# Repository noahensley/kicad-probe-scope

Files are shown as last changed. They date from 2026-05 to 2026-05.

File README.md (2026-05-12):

# ESProbeScope3300

A KiCad PCB design created for ETEC 3300. The board is built around the **ESP32-S2FN4R2** and combines USB-C connectivity, 2.4 GHz Wi-Fi (via an on-board chip antenna), a battery charging circuit, an LDO power rail, an audio amplifier, an LCD interface, RGB status LEDs, and a multi-button probe input — all in a single compact design.

---

## Project structure

```
kicad-probe-scope/
├── ESProbeScope3300.kicad_pcb   # PCB layout
├── ESProbeScope3300.kicad_sch   # Schematic
├── ESProbeScope3300.kicad_pro   # Project file
├── sym-lib-table                # Project-scoped symbol library table
│
├── libs/
│   ├── PartsLibrary3300.kicad_sym       # Symbol library
│   └── PartsLibrary3300.pretty/         # Footprint library
│       └── *.kicad_mod
│
├── fab/
│   ├── gerbers/                 # Copper, mask, silkscreen, edge cuts
│   ├── ESProbeScope3300-PTH.drl
│   ├── ESProbeScope3300-NPTH.drl
│   └── ESProbeScope3300-job.gbrjob
│
└── doc/
    ├── schematic.pdf
    └── bom.xlsx
```

---

## Schematic

A PDF export of the schematic is available at [doc/schematic.pdf](doc/schematic.pdf) for viewing without KiCad.

---

## Key components

| Ref | Part | Function |
|-----|---|---|
| U1 | ESP32-S2FN4R2 | Main MCU with integrated 2.4 GHz Wi-Fi |
| ANT1 | Johanson 2450AT42B100E | 2.4 GHz chip antenna |
| J1 | GCT USB4110-GF-A | USB 2.0 Type-C connector |
| IC3 | MPS MP2664GG | Li-ion battery charger |
| IC1, IC2 | XC8110AA01MR-G | LDO voltage regulators |
| VR1 | ON Semi NCP114ASN330T1G | 3.3 V LDO |
| IC4 | PAM8301 | Class-D audio amplifier |
| LCD1 | Molex 527450897 | LCD flex connector |
| XTAL1 | EXS00A-CS14526 | Crystal oscillator |
| LED1, LED2 | B38G3RGB-10D0003H2U1930 | RGB status LEDs |
| S1–S8 | Alps SKRPABE010 | Tactile pushbuttons |
| SW1 | C&K JS102011SAQN | Slide power switch |
| X3 | — | Probe input header |

---

## Footprint and symbol libraries

All symbols and footprints are in `libs/PartsLibrary3300.kicad_sym` and `libs/PartsLibrary3300.pretty/`. Both are linked via `${KIPRJMOD}` in `sym-lib-table` and the project footprint library table, so they resolve automatically when the project is opened in KiCad regardless of where it is cloned.

Footprints originate from the KiCad standard library, SnapEDA, and manufacturer-published CAD data (Johanson Technology, Walsin, Molex, GCT). Attribution is noted in the footprint description fields within the library files themselves.

---

## License

MIT — see [LICENSE](LICENSE).

---

## Acknowledgements

- [KiCad EDA](https://www.kicad.org/) and the KiCad Libraries contributors
- [SnapEDA](https://www.snapeda.com) for component models
- Johanson Technology, Walsin Technology, Molex, GCT, and other component manufacturers for publishing CAD data

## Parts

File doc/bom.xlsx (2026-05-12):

ETEC3300 Project 2026 — Bill of Materials
Item # | *Ref Des | *Qty | Manufacturer | *Mfg Part # | Description / Value | *Package | Type
1 | ANT1 | 1 | Johanson Technology Inc. | 2450AT42B100 | RF ANTENNA Chip Solder Surface Mount | Custom SMT 2450AT42B100 | SMD
2 | C1, C2, C5, C13, C17 | 5 | Walsin Technology Corporation | 0603B105K250CT | 1 µF ±10% 25V Ceramic Capacitor X7R 0603 (1608 Metric) | C0603 | SMD
3 | C3 | 1 | Cal-Chip Electronics, Inc. | GMC02CG1R0C50NT | 1 pF ±0.25pF 50V Ceramic Capacitor C0G, NP0 0201 (0603 Metric) | C0603 | SMD
4 | C4 | 1 |  |  | DNP | C0603 | DNP
5 | C6 | 1 | Walsin Technology Corporation | 0603B101K500CT | 100 pF ±10% 50V Ceramic Capacitor X7R 0603 (1608 Metric) | C0603 | SMD
6 | C7, C12, C22, C25 | 4 | Cal-Chip Electronics, Inc. | GMC21X5R106M6R3NT | 10 µF ±20% 6.3V Ceramic Capacitor X5R 0805 (2012 Metric) | C0805 | SMD
7 | C8, C9, C11, C14, C15, C16, C19, C20, C23, C24, C26 | 11 | Walsin Technology Corporation | 0603B104M500CT | 0.1 µF ±20% 50V Ceramic Capacitor X7R 0603 (1608 Metric) | C0603 | SMD
8 | C10 | 1 | Taiyo Yuden | LMK107BJ475KA-T | 4.7 µF ±10% 10V Ceramic Capacitor X5R 0603 (1608 Metric) | C0603 | SMD
9 | C18, C21 | 2 | Walsin Technology Corporation | 0603N150J500CT | 15 pF ±5% 50V Ceramic Capacitor C0G, NP0 0603 (1608 Metric) | C0603 | SMD
10 | D1 | 1 | Diodes Incorporated | DDZ9684Q-7 | Zener Diode 3.3 V 500 mW ±5% Surface Mount SOD-123 | SOD123 | SMD
11 | IC1, IC5 | 2 | Torex Semiconductor Ltd | XC8110AA01MR-G | Power Switch/Driver 1:1 P-Channel 500mA SOT-25 | SOT25 | SMD
12 | IC2 | 1 | Monolithic Power Systems Inc. | MP2664GG-0000-Z | Charger IC Lithium Ion/Polymer 10-QFN (2x2) | QFN10 | SMD
13 | IC3 | 1 | Espressif Systems | ESP32-S2FH4 | WiFi 802.11b/g/n Transceiver Module 2.4GHz Antenna Not Included Surface Mount | 56-VFQFN Exposed Pad | SMD
14 | IC4 | 1 | Diodes Incorporated | PAM8301AAF | Amplifier IC 1-Channel (Mono) Class D SOT-23-6 | SOT23-6 | SMD
15 | L1 | 1 | Johanson Technology Inc. | LRC0402CS3N3GV001T | 3.3 nH Unshielded Multilayer Inductor 300 mA 190mOhm Max 0402 (1005 Metric) | L0402 | SMD
16 | L2 | 1 | Johanson Technology Inc. | LRC0603CS1N5GV001T | 1.5 nH Unshielded Multilayer Inductor 300 mA 100mOhm Max 0603 (1608 Metric) | L0603 | SMD
17 | LCD1 | 1 | Molex | 527450897 | 8 Position Connector Contacts, Top 0.020" (0.50mm) Surface Mount, Right Angle | MOLEX_FPC_527450897 | SMD
18 | LED1, LED2 | 2 | Harvatek Corporation | B38G3RGB-10D0003H2U1930 | Red, Green, Blue (RGB) LED Indication - Discrete 2V Red, 3V Green, 3V Blue 0606 (1616 Metric) | 0606_RGB_LED | SMD
19 | PROBE | 1 |  | DNP | - | MA03-2-05_3x2_1.27MM_PITCH_MALE_PIN_HEADER | DNP
20 | R1 | 1 | YAGEO | RC0603FR-070RL | 0 Ohms Jumper 0.1W, 1/10W Chip Resistor 0603 (1608 Metric) Moisture Resistant Thick Film | R0603 | 0603 (1608 Metric)
21 | R2, R3, R19, R20 | 4 | YAGEO | RC0603FR-07100KL | 100 kOhms ±1% 0.1W, 1/10W Chip Resistor 0603 (1608 Metric) Moisture Resistant Thick Film | R0603 | 0603 (1608 Metric)
22 | R4 | 1 | YAGEO | RC0603FR-07300KL | 300 kOhms ±1% 0.1W, 1/10W Chip Resistor 0603 (1608 Metric) Moisture Resistant Thick Film | R0603 | 0603 (1608 Metric)
23 | R5, R6 | 2 | YAGEO | RC0603FR-075K1L | 5.1 kOhms ±1% 0.1W, 1/10W Chip Resistor 0603 (1608 Metric) Moisture Resistant Thick Film | R0603 | 0603 (1608 Metric)
24 | R8, R7, R9, R10, R11, R12, R22 | 7 | YAGEO | RC0603FR-0710KL | 10 kOhms ±1% 0.1W, 1/10W Chip Resistor 0603 (1608 Metric) Moisture Resistant Thick Film | R0603 | 0603 (1608 Metric)
25 | R13, R14, R15, R16, R17, R18, R23 | 7 | YAGEO | RC0603FR-071KL | 1 kOhms ±1% 0.1W, 1/10W Chip Resistor 0603 (1608 Metric) Moisture Resistant Thick Film | R0603 | 0603 (1608 Metric)
26 | R21 | 1 | YAGEO | RC0603FR-0722RL | 22 Ohms ±1% 0.1W, 1/10W Chip Resistor 0603 (1608 Metric) Moisture Resistant Thick Film | R0603 | 0603 (1608 Metric)
27 | S0, S1, S2, S3, S4, SW_BOOT, SW_PWR, SW_RST | 8 | Alps Alpine | SKRPABE010 | Tactile Switch SPST-NO Top Actuated Surface Mount | ALPS_TACT_SKRPABE010 | SMD
28 | SPK | 1 | Molex | 53047-02 | Connector Header Through Hole 2 position 0.049" (1.25mm) | 53047-02 | TH
29 | SW1 | 1 | C&K | JS102011SAQN | Slide Switch SPDT Surface Mount, Right Angle | JS102011SAQN | SMD
30 | VR1 | 1 | onsemi | NCP114 | Linear Voltage Regulator IC Positive Fixed 1 Output 300mA 5-TSOP | TSOP-5 | SMD
31 | X1 | 1 |  | USBC_GCT_USB4110 |  | USBC_GCT_USB4110
32 | X2 | 1 | JST Sales America Inc. | B2B-PH-K-S | Connector Header Through Hole 2 position 0.079" (2.00mm) | B2B-PH-K-S_2MM_JST_CONNECTOR | TH
33 | X3 | 1 | Harwin Inc. | M20-9950245 | Connector Header Through Hole, Right Angle 4 position 0.100" (2.54mm) | MA02-2_2x2_RA_Male_Header | TH
34 | XTAL | 1 | NDK (NIHON DEMPA KOGYO CO., LTD) | NX3225SA | 32 MHz ±15ppm Crystal 8pF 50 Ohms 4-SMD, No Lead | SMT_CRYSTAL_NX3225 | SMD

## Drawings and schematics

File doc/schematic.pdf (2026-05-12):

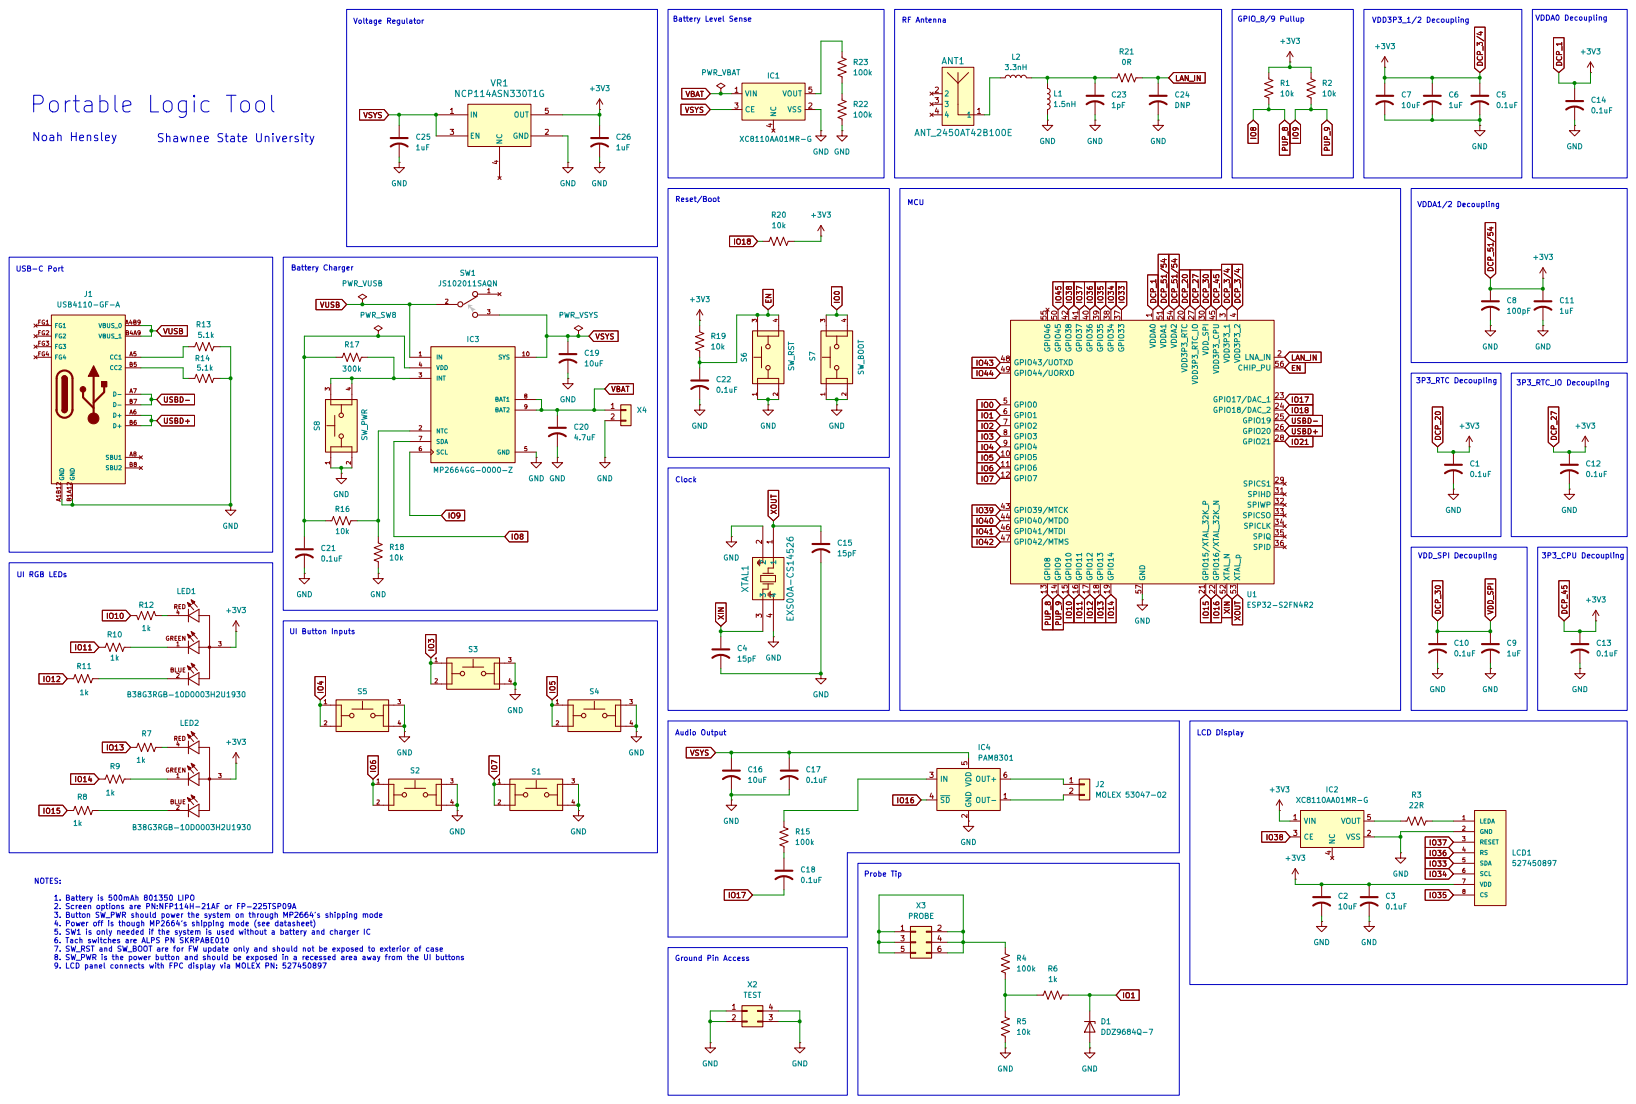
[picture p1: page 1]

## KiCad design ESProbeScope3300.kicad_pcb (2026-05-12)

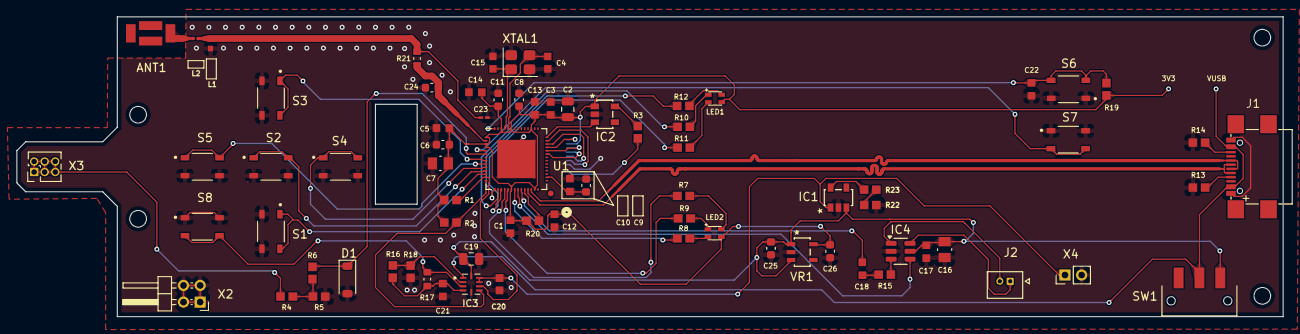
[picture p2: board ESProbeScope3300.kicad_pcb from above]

Board: 2 copper layers, 152.1 x 36.0 mm, 77 parts (1 on the bottom side), 59 nets.

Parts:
ANT1: ANT_2450AT42B100E; ANT_2450AT42B100E_JOT
C1, C3, C5, C10, C12, C13, C14, C17, C18, C21, C22: 0.1uF; CAP_0603_X_WAL
C2, C19: 10uF; C_0805_2012Metric
C4, C15: 15pF; CAP_0603_S_WAL
C6, C9, C11, C25, C26: 1uF; C_0603_1608Metric
C7, C16: 10uF; CAP_GMC21_1.50H_CCE
C8: 100pF; C_0603_1608Metric
C20: 4.7uF; CAPC1608X90N
C23: 1pF; CAP_GMC02_CCE
C24: DNP; C_0603_1608Metric
D1: DDZ9684Q-7; D_SOD-123
IC1, IC2: XC8110AA01MR-G
IC3: MP2664GG-0000-Z; QFN50P200X200X105-10N
IC4: PAM8301; SOT-23-6
J1: USB4110-GF-A
J2: MOLEX 53047-02; MOLEX_530470210
L1: 1.5nH; IND_L-07C3N3SV6T_JOT
L2: 3.3nH; L_0201_0603Metric
LCD1: 527450897; CONN_527450897_MOL
LED1, LED2: B38G3RGB-10D0003H2U1930; B38G3RGB-10D0003H2U1930_0606_RGB_LED
R1, R2, R5, R16, R18, R19, R20: 10k; RESC1607X60N
R3: 22R; RESC1607X60N
R4, R15, R22, R23: 100k; RESC1607X60N
R6, R7, R8, R9, R10, R11, R12: 1k; RESC1607X60N
R13, R14: 5.1k; RESC1607X60N
R17: 300k; RESC1608X55N
R21: 0R; RESC1608X55N
S1, S2, S3, S4, S5: SKRPABE010; SW_SKRPABE010
S6: SW_RST; SW_SKRPABE010
S7: SW_BOOT; SW_SKRPABE010
S8: SW_PWR; SW_SKRPABE010
SW1: JS102011SAQN; SW_JS102011SAQN
U1: ESP32-S2FN4R2; ESP32-S2FN4R2_QFN56
VR1: NCP114ASN330T1G; NCP114ASN330T1G_5-TSOP
X2: TEST; PinHeader_2x02_P2.00mm_Horizontal
X3: PROBE; PinHeader_2x03_P1.27mm_Vertical
X4: Conn_01x02; PinHeader_1x02_P2.00mm_Vertical
XTAL1: EXS00A-CS14526; Crystal_SMD_WE_CFPX-180-4Pin_3.2x2.5mm

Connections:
DCP_1: C1.1, C2.1, C3.1, C5.1, C6.1, C7.1, C8.1, C11.1, C12.1, C13.1, C14.1, C26.1, IC2.1 (VIN), LCD1.7 (VDD), LED1.3, LED2.3, R1.1, R2.1, R19.1, R20.2, U1.1 (VDDA0), U1.3 (VDD3P3_1), U1.4 (VDD3P3_2), U1.20 (VDD3P3_RTC), U1.27 (VDD3P3_RTC_IO), U1.45 (VDD3P3_CPU), U1.51 (VDDA1), U1.54 (VDDA2), VR1.5 (OUT)
DCP_30: C9.1, C10.1, U1.30 (VDD_SPI)
EN: C22.1, R19.2, S6.3, S6.4, U1.56 (CHIP_PU)
GND: C1.2, C2.2, C3.2, C4.2, C5.2, C6.2, C7.2, C8.2, C9.2, C10.2, C11.2, C12.2, C13.2, C14.2, C15.2, C16.2, C17.2, C19.2, C20.2, C21.2, C22.2, C23.2, C24.2, C25.2, C26.2, D1.2 (A), IC1.2 (VSS), IC2.2 (VSS), IC3.5 (GND), IC4.2 (GND), J1.A1B12 (GND), J1.B1A12 (GND), L1.2, LCD1.2 (GND), R5.2, R13.1, R14.1, R18.2, R22.2, S1.3, S1.4, S2.3, S2.4, S3.3, S3.4, S4.3, S4.4, S5.3, S5.4, S6.1, S6.2, S7.1, S7.2, S8.1, S8.2, U1.57 (GND), VR1.2 (GND), X2.1, X2.2, X2.3, X2.4, X4.2, XTAL1.2, XTAL1.4
IO0: S7.3, S7.4, U1.5 (GPIO0)
IO1: D1.1 (K), R6.1, U1.6 (GPIO1)
IO3: S3.1, S3.2, U1.8 (GPIO3)
IO4: S5.1, S5.2, U1.9 (GPIO4)
IO5: S4.1, S4.2, U1.10 (GPIO5)
IO6: S2.1, S2.2, U1.11 (GPIO6)
IO7: S1.1, S1.2, U1.12 (GPIO7)
IO8: IC3.7 (SDA), R1.2, U1.13 (GPIO8)
IO9: IC3.6 (SCL), R2.2, U1.14 (GPIO9)
IO10: R12.1, U1.15 (GPIO10)
IO11: R10.1, U1.16 (GPIO11)
IO12: R11.1, U1.17 (GPIO12)
IO13: R7.1, U1.18 (GPIO13)
IO14: R9.1, U1.19 (GPIO14)
IO15: R8.1, U1.21 (GPIO15/XTAL_32K_P)
IO16: IC4.4 (~SD), U1.22 (GPIO16/XTAL_32K_N)
IO17: C18.2, U1.23 (GPIO17/DAC_1)
IO18: R20.1, U1.24 (GPIO18/DAC_2)
IO33: LCD1.5 (SDA), U1.37 (GPIO33)
IO34: LCD1.6 (SCL), U1.38 (GPIO34)
IO35: LCD1.8 (CS), U1.39 (GPIO35)
IO36: LCD1.4 (RS), U1.40 (GPIO36)
IO37: LCD1.3 (RESET), U1.41 (GPIO37)
IO38: IC2.3 (CE), U1.42 (GPIO38)
LAN_IN: C24.1, R21.2, U1.2 (LNA_IN)
unnamed: ANT1.1, L2.1
unnamed: C18.1, R15.2
unnamed: C23.1, L1.1, L2.2, R21.1
unnamed: IC1.5 (VOUT), R23.1
unnamed: IC2.5 (VOUT), R3.1
unnamed: IC3.3 (INT), R17.2, S8.3, S8.4
unnamed: IC3.2 (NTC), R16.2, R18.1
unnamed: C21.1, IC3.4 (VDD), R16.1, R17.1
unnamed: IC4.3 (IN), R15.1
unnamed: IC4.6 (OUT+), J2.1
unnamed: IC4.1 (OUT-), J2.2
unnamed: J1.A5 (CC1), R13.2
unnamed: J1.B5 (CC2), R14.2
unnamed: LCD1.1 (LEDA), R3.2
unnamed: LED1.1, R10.2
unnamed: LED1.2, R11.2
unnamed: LED1.4, R12.2
unnamed: LED2.1, R9.2
unnamed: LED2.2, R8.2
unnamed: LED2.4, R7.2
unnamed: R4.2, R5.1, R6.2
unnamed: R22.1, R23.2
unnamed: R4.1, X3.1, X3.2, X3.3, X3.4, X3.5, X3.6
USBD+: J1.A6 (D+), J1.B6 (D+), U1.26 (GPIO20)
USBD-: J1.A7 (D-), J1.B7 (D-), U1.25 (GPIO19)
VBAT: C20.1, IC1.1 (VIN), IC3.8 (BAT1), IC3.9 (BAT2), X4.1
VSYS: C16.1, C17.1, C19.1, C25.1, IC1.3 (CE), IC3.10 (SYS), IC4.5 (VDD), SW1.3, VR1.1 (IN), VR1.3 (EN)
VUSB: IC3.1 (IN), J1.A4B9 (VBUS_0), J1.B4A9 (VBUS_1), SW1.2
XIN: C4.1, U1.52 (XTAL_N), XTAL1.3
XOUT: C15.1, U1.53 (XTAL_p), XTAL1.1

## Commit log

2026-05-12 Initial commit of project files.
    [ESProbeScope3300-B_Cu.gbl, ESProbeScope3300-B_Mask.gbs, ESProbeScope3300-B_Paste.gbp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]
2026-05-12 Modified structure, added README and License information.
    [ESProbeScope3300-B_Cu.gbl, ESProbeScope3300-B_Mask.gbs, ESProbeScope3300-B_Paste.gbp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]
2026-05-12 Added schematic PDF.
2026-05-12 Added reference to schematic PDF.
